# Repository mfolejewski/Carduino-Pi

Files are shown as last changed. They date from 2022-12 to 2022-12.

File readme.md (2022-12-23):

# Carduino Pi - Raspberry Pi RP2040 board with business card form factor and compatible with Arduino Uno

## Description
Carduino Pi is a Raspberry Pi RP2040 evaluation board with business card form factor and compatible with Arduino Uno standard, which has features, as following:
- PCB dimensions: 85,60 x 54,00 mm (ultra flat design, only 0.8mm components height),
- all 30 GPIO pins connected to pin header (Arduino Uno standard with extra 8 GPIO pins),
- 2-layer PCB board,
- onboard: QSPI Flash (USON8 package), 12MHz oscillator, PWR LED,
- RESET/BOOT switches,
- USB interface (PCB edge connector) for debugging MCU and for flashing SPI memory,
- 8x ring LED RGB (WS2812-2020 diodes), 
- fully open source project (OSHW).

Here you can find:
- \Python: simple script do test RGB ring LED (use Thonny IDE)
- \Manufacturing files: all the production files for PCB ordering and assembly at JLCPCB (Gerber files, Pick & Place, BOM, etc.)
- \source files: source files in Altium Designer format (KiCad: TBD)

The equation is very simple:
Business Card + Arduino + Raspberry Pi RP2040 = Carduino Pi

## License
Project published as Open Source Hardware (OSHW) under CERN OHL v1.2 (Open Hardware Licence).



Project has been certified as Open Source Hardware by the Open Source Hardware Association (OSHWA).

UID is: PL000013

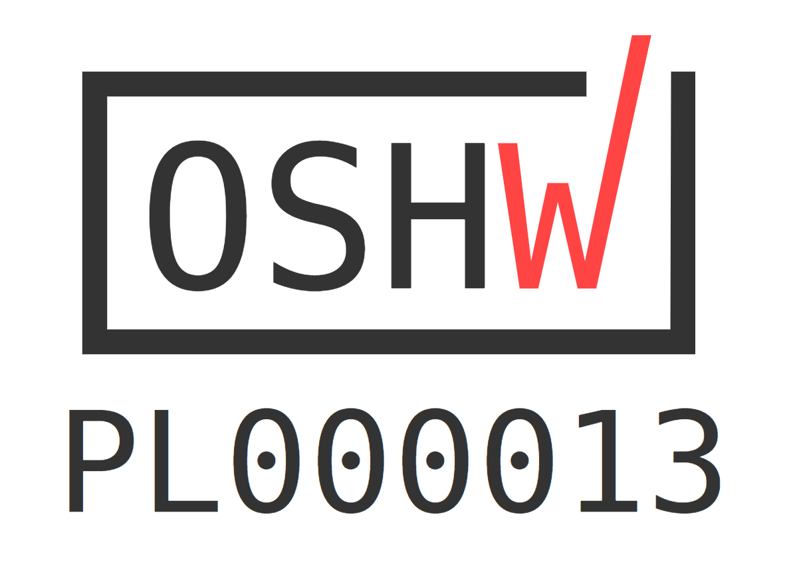
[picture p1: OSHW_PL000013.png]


https://certification.oshwa.org/pl000013.html

## Press release
TBD

## Photos
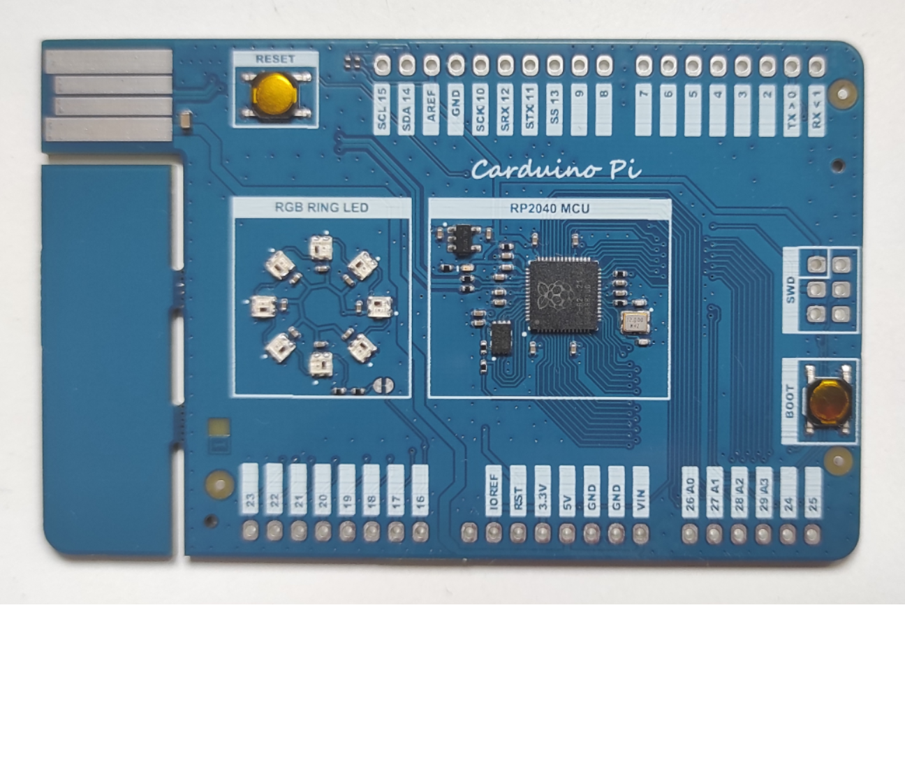
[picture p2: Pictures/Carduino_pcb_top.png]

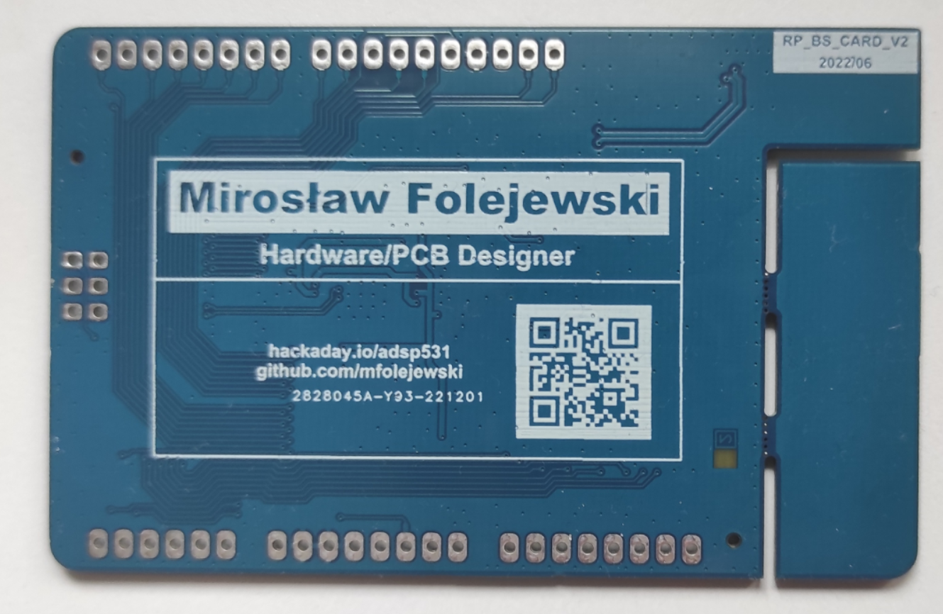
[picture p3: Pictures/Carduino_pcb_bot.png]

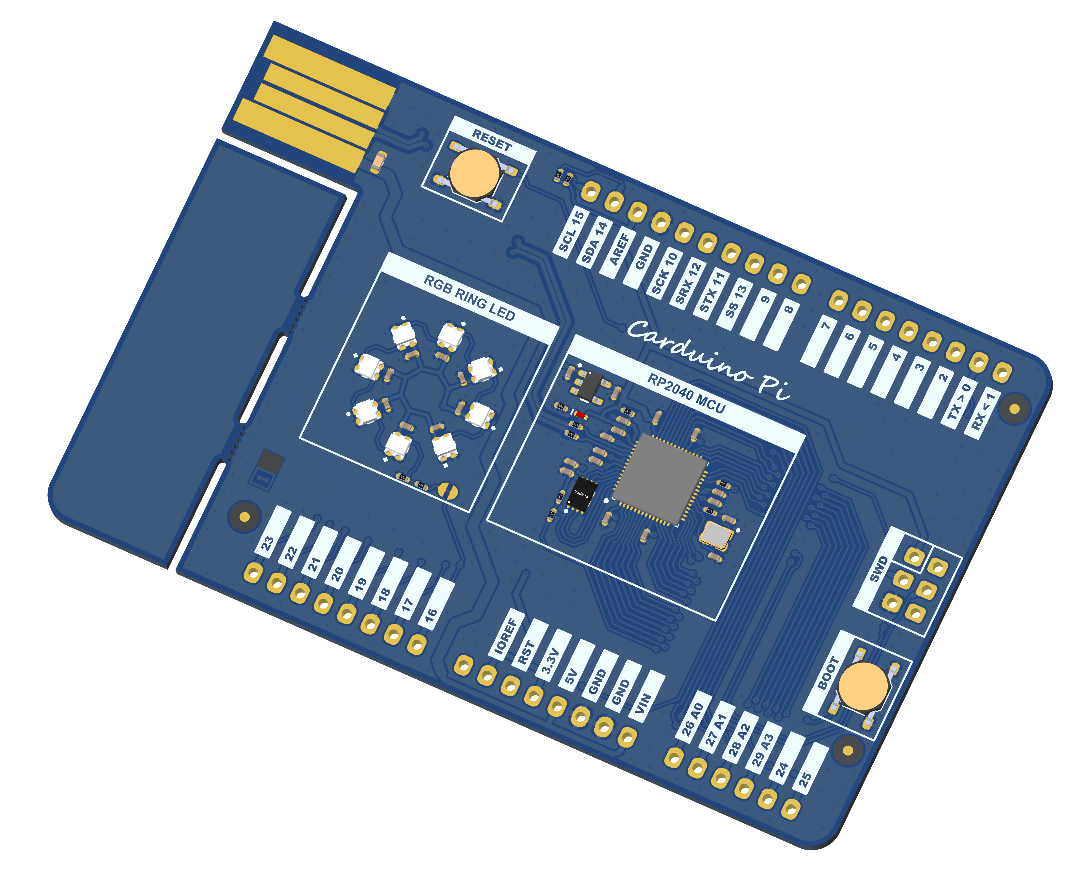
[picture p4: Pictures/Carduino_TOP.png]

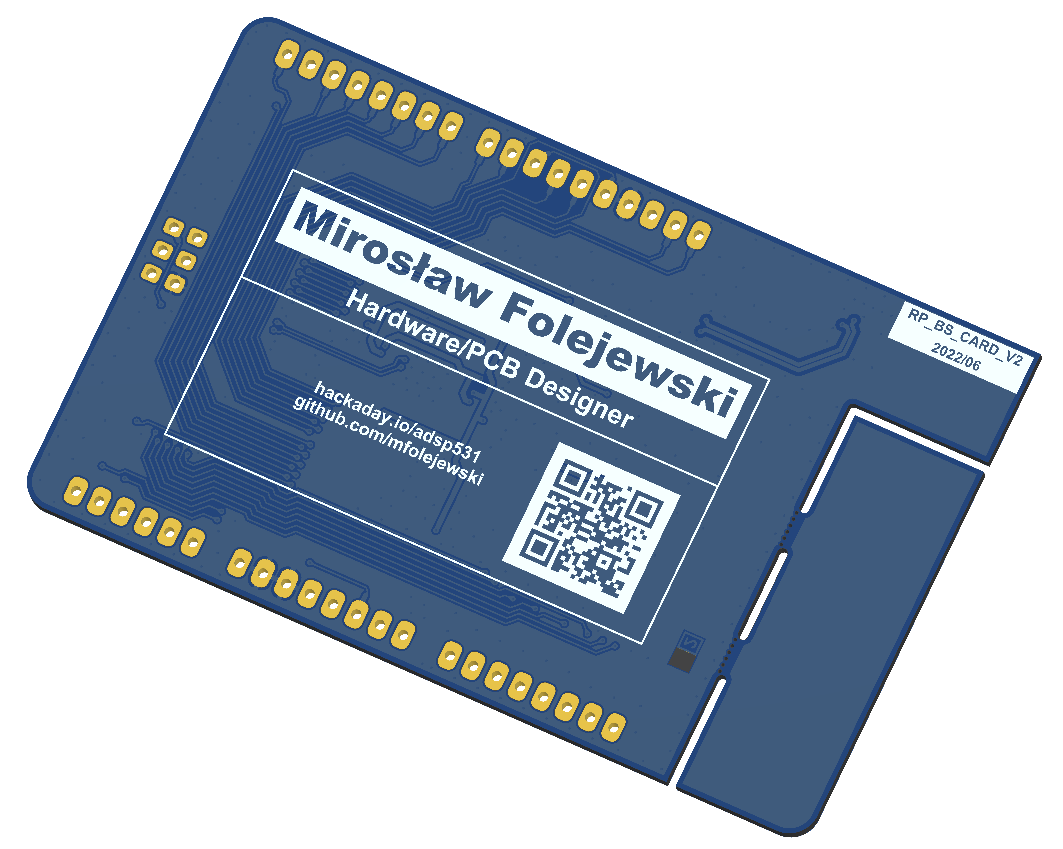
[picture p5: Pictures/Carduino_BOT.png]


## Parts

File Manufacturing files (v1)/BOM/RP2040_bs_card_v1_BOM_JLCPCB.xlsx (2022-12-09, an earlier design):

Comment | Designator | Footprint | Supplier Part Number 1
1k | R5, R6 | 0402 (1005) | C106235
2k | R33 | 0402 (1005) | C60488
2.2uF | C1, C2, C4, C15, C16, C17 | 0402 (1005) | C107371
4.7k | R37, R38 | 0402 (1005) | C105871
10k | R3, R4, R9 | 0402 (1005) | C60490
12.000MHz | X1 | SMD 2520 | C2149205
15pF | C5, C6 | 0402 (1005) | C106997
27R | R1, R2 | 0402 (1005) | C138021
47uF | C18 | 0603 (1608) | C140782
100nF | C3, C7, C8, C9, C10, C11, C12, C13, C14, C19, C20, C21, C22, C23, C24, C25, C26 | 0402 (1005) | C155422
100R | R7, R8 | 0402 (1005) | C106232
NCP114ASN330T1G | U3 |  | C457666
Red | LED26 | 0402 (1005) | C965790
RP2040 | U1 | QFN-56 | C2040
TACT Switch | SW1, SW2 | 3780595 | C2681473
W25Q64JV | U2 |  | C2843335
WS2812B-2020 | D1, D2, D3, D4, D5, D6, D7, D8 | SMD 2020 | C965555

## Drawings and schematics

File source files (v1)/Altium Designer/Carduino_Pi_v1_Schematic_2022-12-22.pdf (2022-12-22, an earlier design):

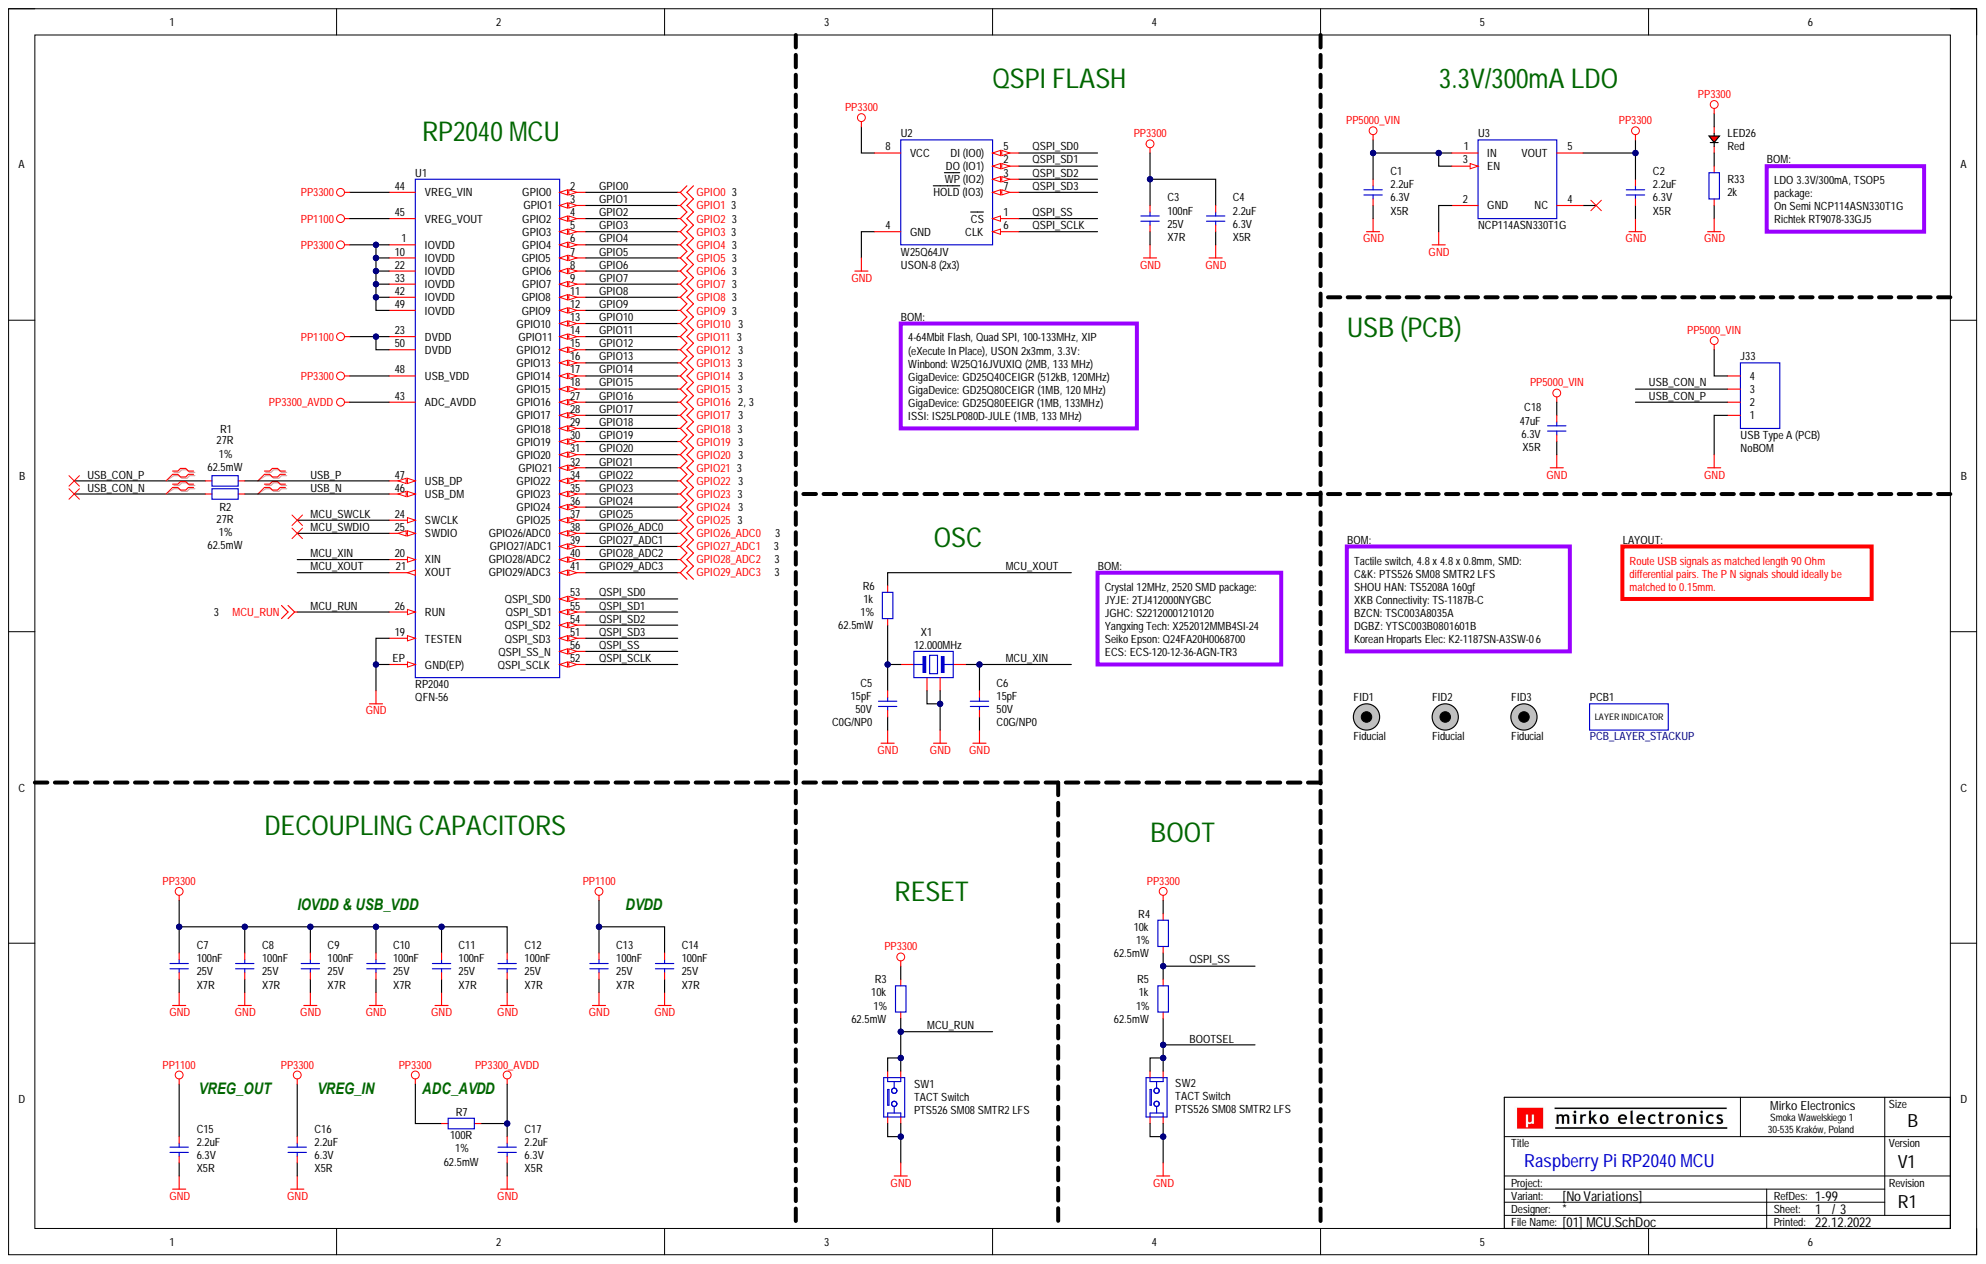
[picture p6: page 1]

OVDD 33
OVDD 42

Route USB signals as
matched

rs. The P N signals should

GND(EP) EP QFN-56

Mirko Electronics Smoka Wawe l ski ego 1 30-535 Kra kó w, Pol a nd | Size B

Ti tl e Ra spberry Pi RP 2040 MCU | | Version V 1

Project: | | Revision R1
Variant: [No Var iations] | RefDes: 1-99
Designer: * | Sheet:
Fi le Name: [01] MCU.SchDoc | Printed:

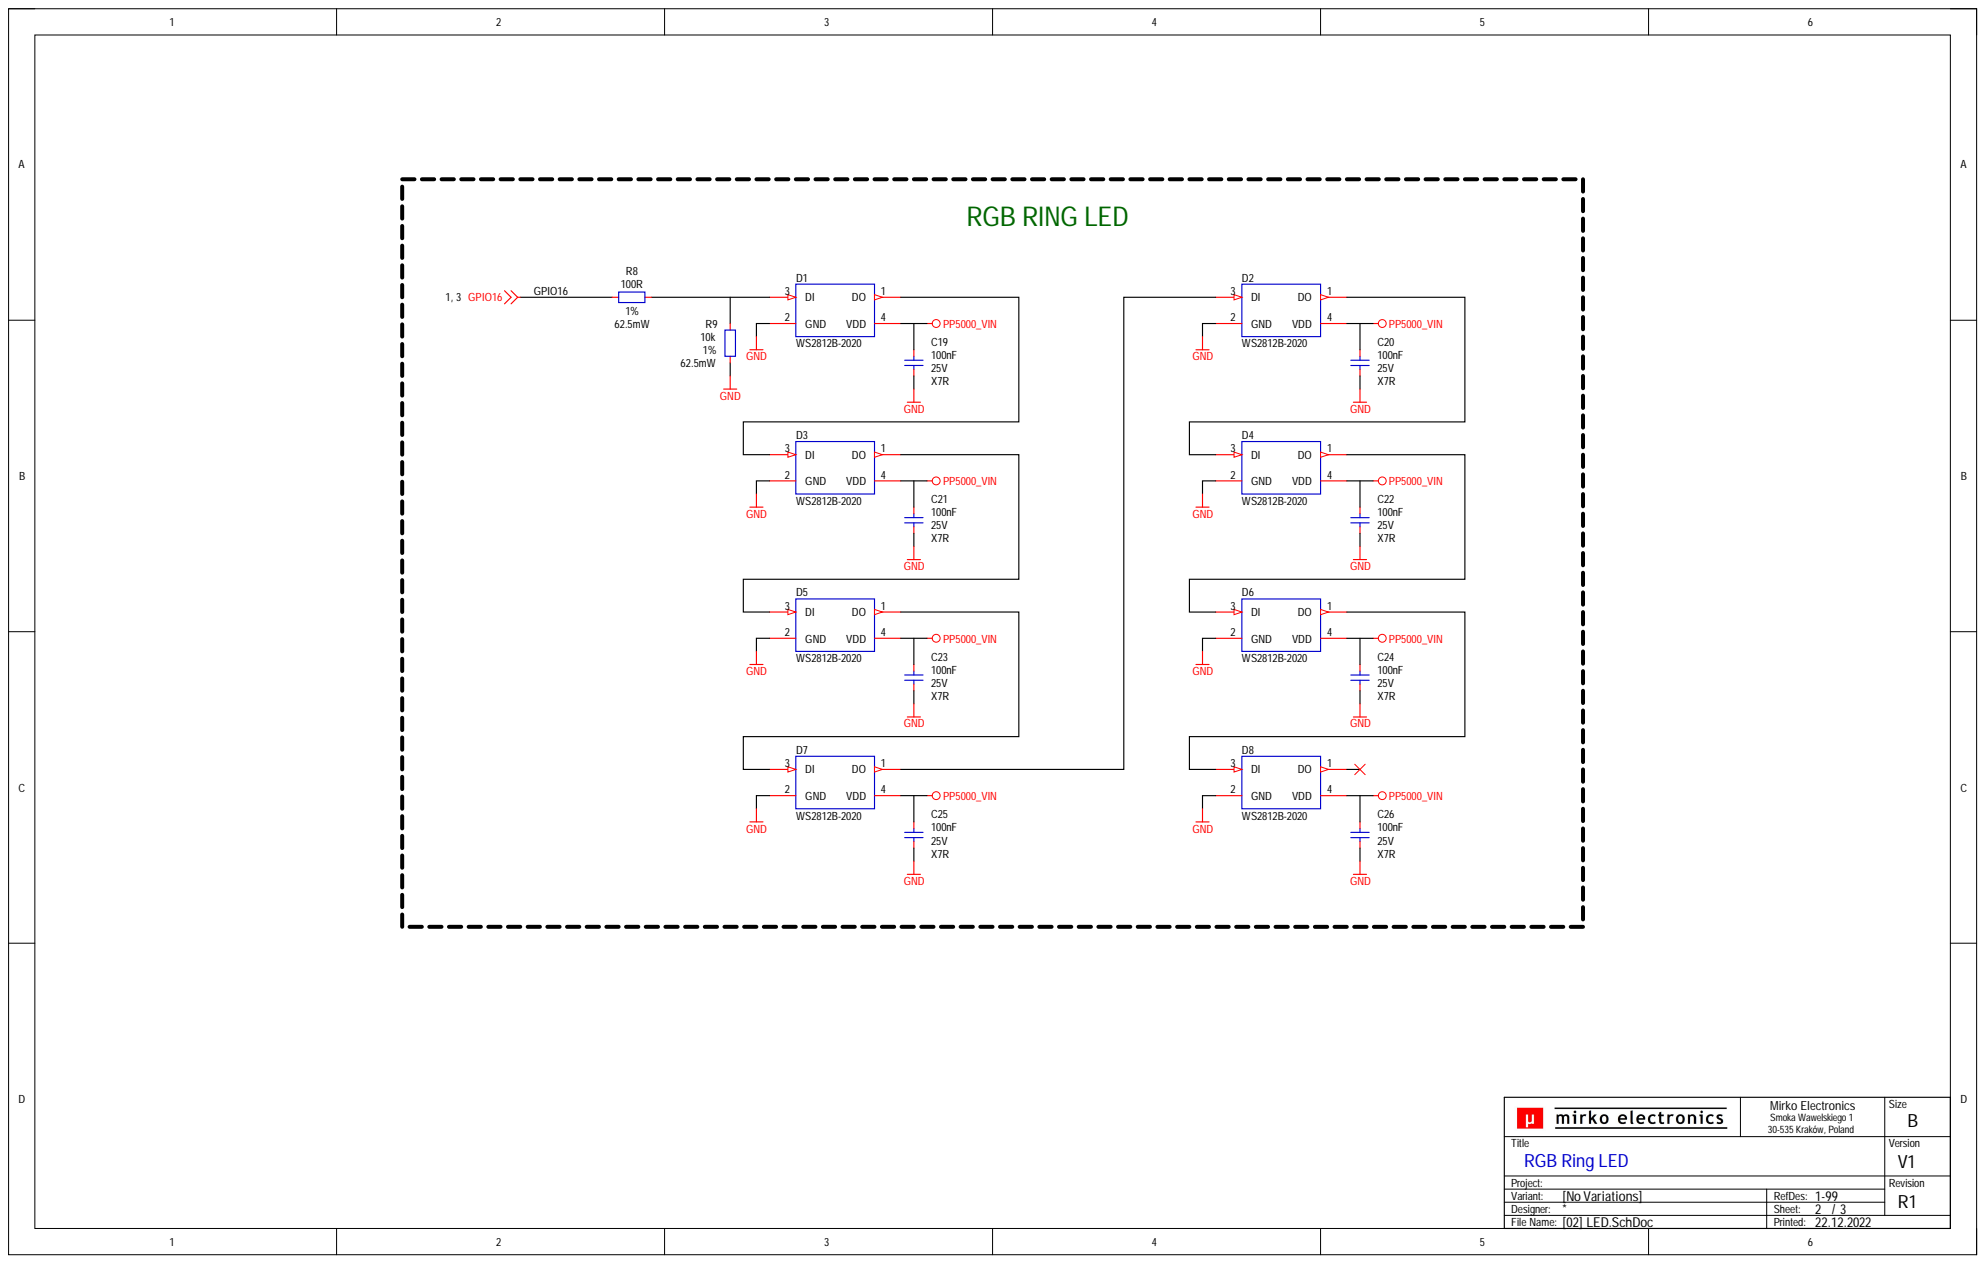
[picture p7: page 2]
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

Ti tl e RGB Ring LE D | | Version V 1

Project: | | Revision R1
Variant: [No Var iations] | RefDes: 1-99
Designer: * | Sheet:

[02] LED.SchDoc | Printed:

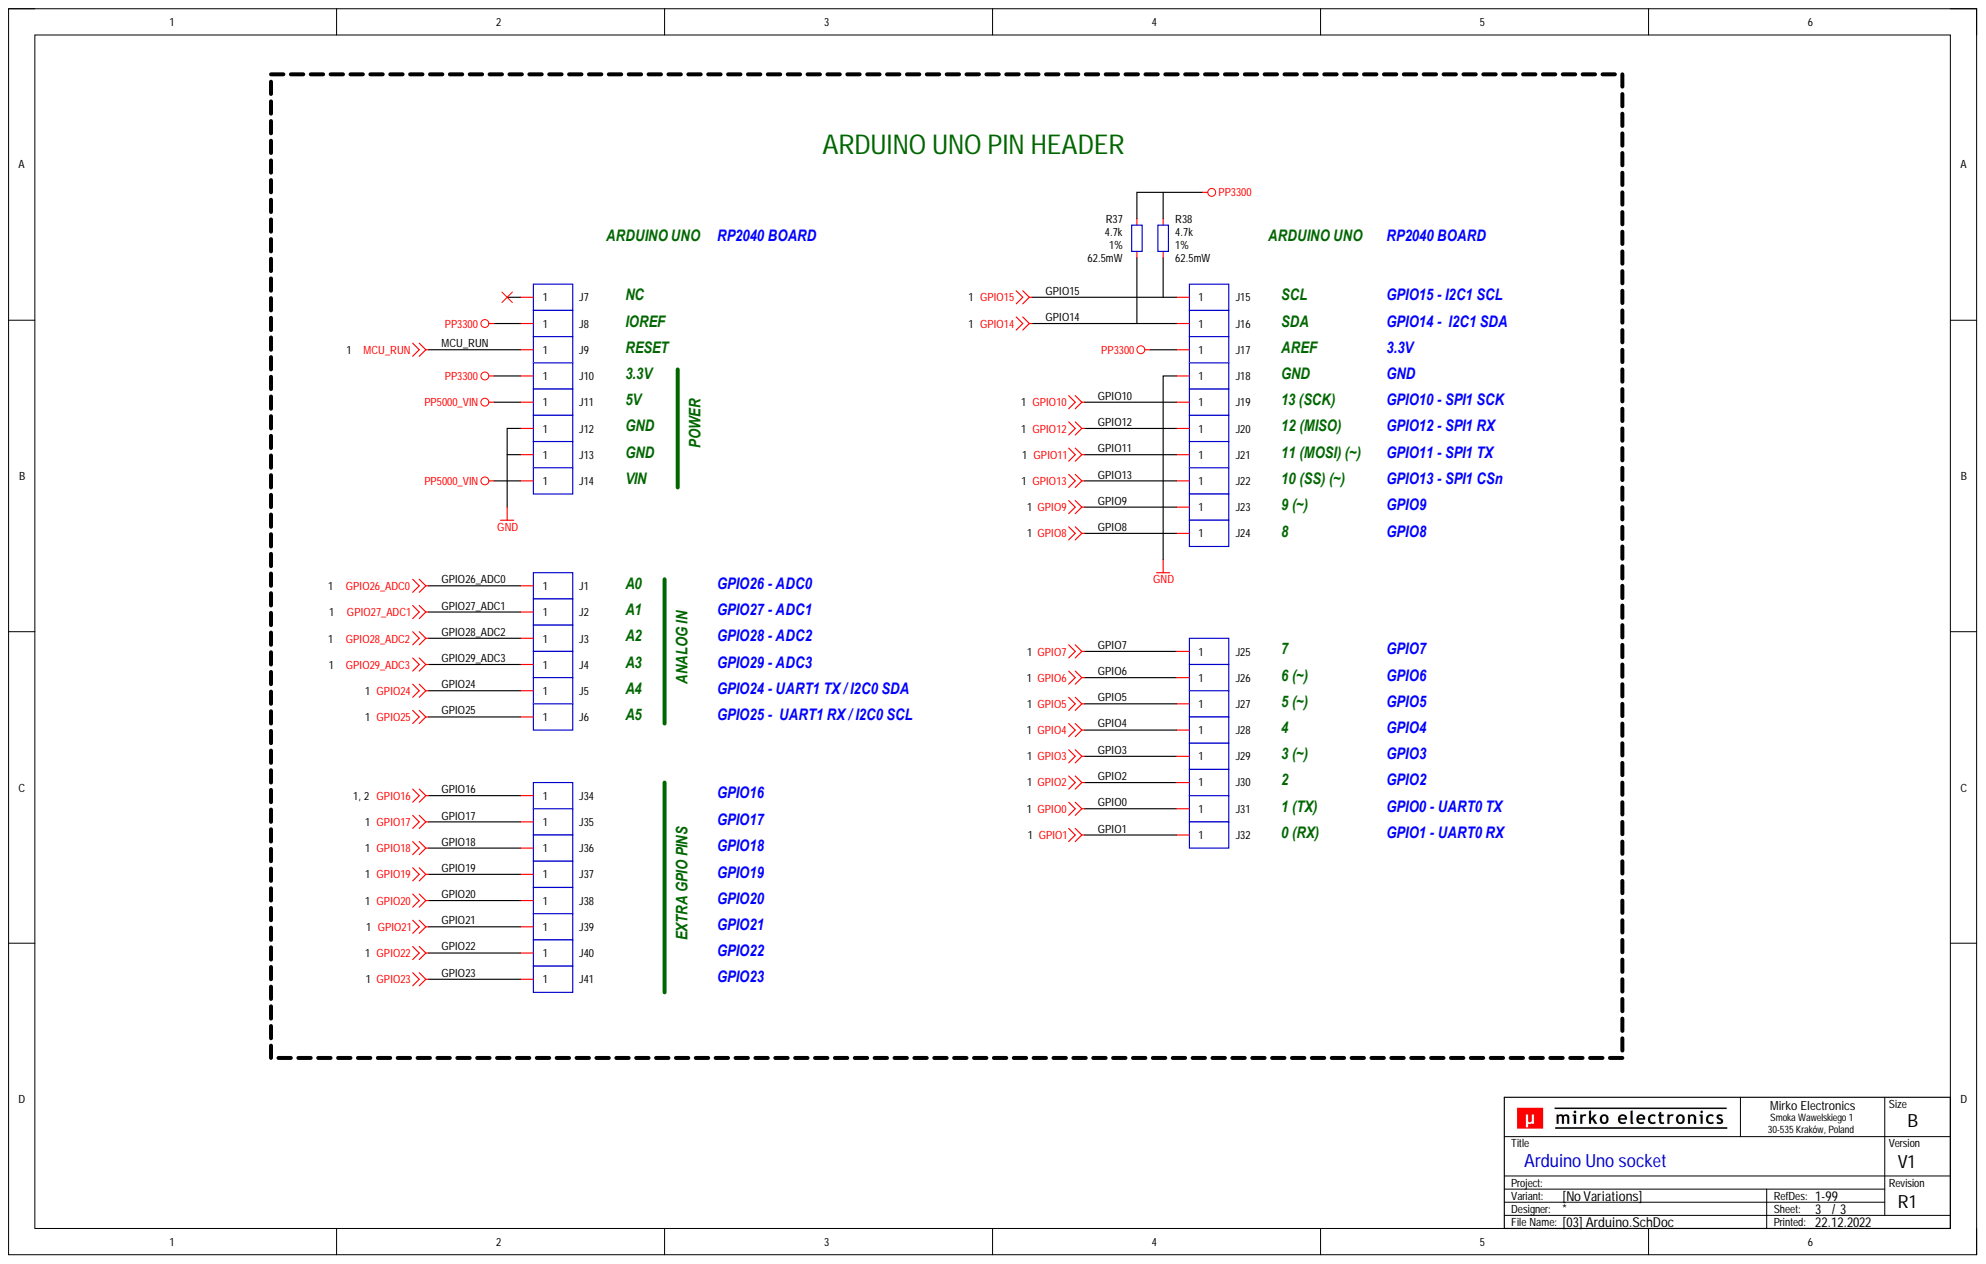
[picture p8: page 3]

ARDUINO UNO PIN HEADER

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

Ti tl e Arduino Uno soc k e t | | Version V 1

Project: | | Revision R1
Variant: [No Var iations] | RefDes: 1-99
Designer: * | Sheet:

[03] Arduino.SchDoc | Printed:

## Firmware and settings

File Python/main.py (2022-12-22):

# Example using PIO to drive a set of WS2812 LEDs.

import array, time
from machine import Pin
import rp2

# Configure the number of WS2812 LEDs.
NUM_LEDS = 8
PIN_NUM = 16
brightness = 0.1

@rp2.asm_pio(sideset_init=rp2.PIO.OUT_LOW, out_shiftdir=rp2.PIO.SHIFT_LEFT, autopull=True, pull_thresh=24)
def ws2812():
    T1 = 2
    T2 = 5
    T3 = 3
    wrap_target()
    label("bitloop")
    out(x, 1)               .side(0)    [T3 - 1]
    jmp(not_x, "do_zero")   .side(1)    [T1 - 1]
    jmp("bitloop")          .side(1)    [T2 - 1]
    label("do_zero")
    nop()                   .side(0)    [T2 - 1]
    wrap()


# Create the StateMachine with the ws2812 program, outputting on pin
sm = rp2.StateMachine(0, ws2812, freq=8_000_000, sideset_base=Pin(PIN_NUM))

# Start the StateMachine, it will wait for data on its FIFO.
sm.active(1)

# Display a pattern on the LEDs via an array of LED RGB values.
ar = array.array("I", [0 for _ in range(NUM_LEDS)])

##########################################################################
def pixels_show():
    dimmer_ar = array.array("I", [0 for _ in range(NUM_LEDS)])
    for i,c in enumerate(ar):
        r = int(((c >> 8) & 0xFF) * brightness)
        g = int(((c >> 16) & 0xFF) * brightness)
        b = int((c & 0xFF) * brightness)
        dimmer_ar[i] = (g<<16) + (r<<8) + b
    sm.put(dimmer_ar, 8)
    time.sleep_ms(10)

def pixels_set(i, color):
    ar[i] = (color[1]<<16) + (color[0]<<8) + color[2]

def pixels_fill(color):
    for i in range(len(ar)):
        pixels_set(i, color)

def color_chase(color, wait):
    for i in range(NUM_LEDS):
        pixels_set(i, color)
        time.sleep(wait)
        pixels_show()
    time.sleep(0.5)
 
def wheel(pos):
    # Input a value 0 to 255 to get a color value.
    # The colours are a transition r - g - b - back to r.
    if pos < 0 or pos > 255:
        return (0, 0, 0)
    if pos < 85:
        return (255 - pos * 3, pos * 3, 0)
    if pos < 170:
        pos -= 85
        return (0, 255 - pos * 3, pos * 3)
    pos -= 170
    return (pos * 3, 0, 255 - pos * 3)
 
 
def rainbow_cycle(wait):
    for j in range(255):
        for i in range(NUM_LEDS):
            rc_index = (i * 256 // NUM_LEDS) + j
            pixels_set(i, wheel(rc_index & 255))
        pixels_show()
        time.sleep(wait)

BLACK = (0, 0, 0)
RED = (255, 0, 0)
YELLOW = (255, 150, 0)
GREEN = (0, 255, 0)
CYAN = (0, 255, 255)
BLUE = (0, 0, 255)
PURPLE = (180, 0, 255)
WHITE = (255, 255, 255)
COLORS = (BLACK, RED, YELLOW, GREEN, CYAN, BLUE, PURPLE, WHITE)

print("fills")
for color in COLORS:       
    pixels_fill(color)
    pixels_show()
    time.sleep(0.5)

print("chases")
for color in COLORS:       
    color_chase(color, 0.05)

print("rainbow")
rainbow_cycle(0)
